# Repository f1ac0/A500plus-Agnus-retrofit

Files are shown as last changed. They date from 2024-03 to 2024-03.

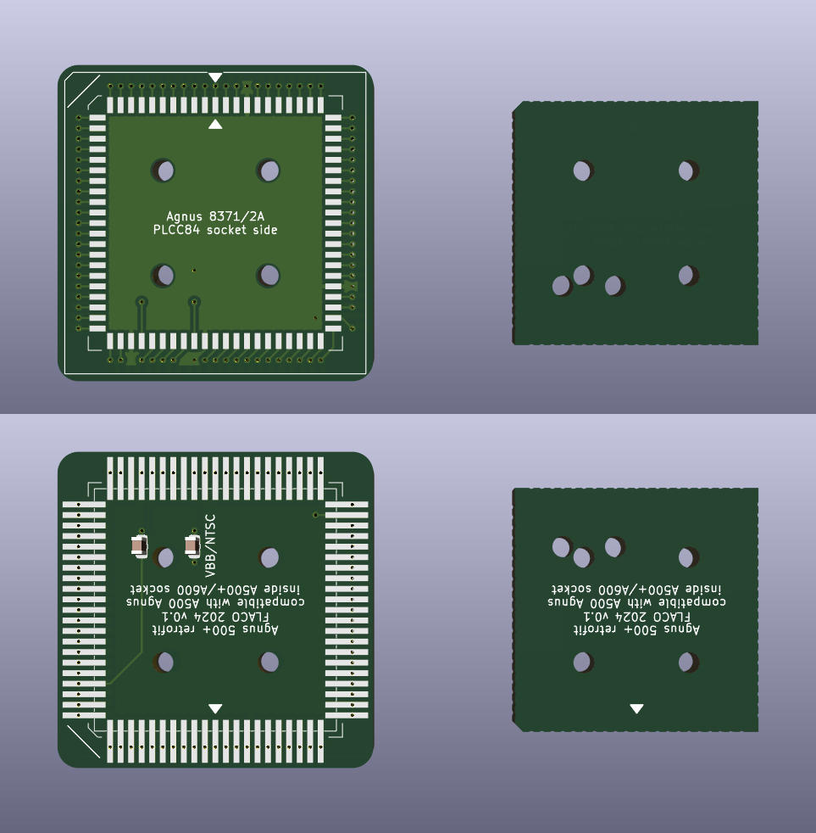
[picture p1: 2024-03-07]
SMD socket version/A500+ Agnus retrofit SMD - FLACO 2024.jpg

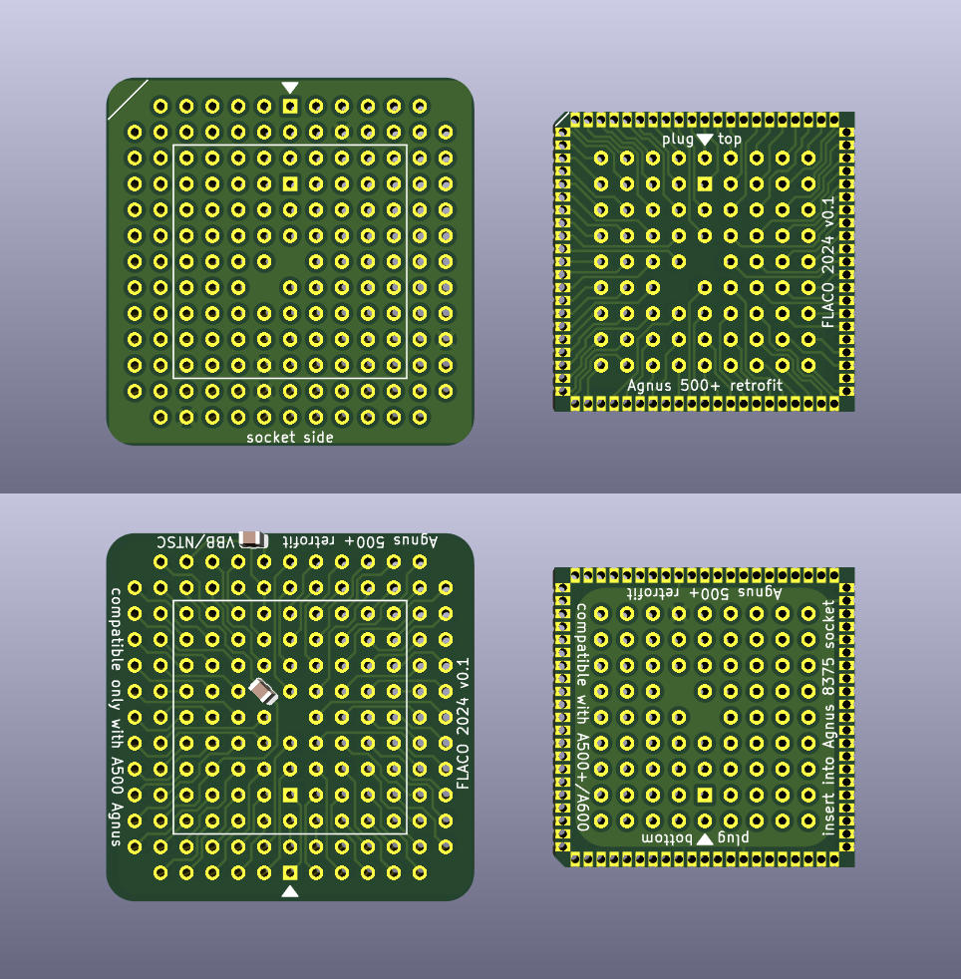
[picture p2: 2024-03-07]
TH socket version/A500+ Agnus retrofit TH - FLACO 2024.jpg

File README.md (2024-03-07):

# A500+ Agnus retrofit
I accidentally zapped my precious 8375 Agnus with ESD on my A500(+) rev8 motherboard, and I am planing to use a cheaper 8371 to continue the development of the Pistorm'X500 and other Amiga projects.

It is based on the same idea as the DietAgnus https://github.com/LIV2/Diet-Agnus-A500-plus except I plan to keep the PLCC84 socket to restore the original system later on. I am also looking forward modern replacement projects such as the ReAgnus https://github.com/jbilander/ReAgnus or https://github.com/jbilander/ReAgnus-MegAChip.

There are two versions in this repository :
- The Through Hole version was the first one I designed : it is based on a TH PLCC84 socket connected to a "plug" PCB using standard 2.54mm pin headers ; to ensure the contact with the motherboard socket, the plug PCB needs to mimic the PLCC "legs" with the addition of single core wires soldered from each top pad to its bottom counterpart all around the edges.
- The SMD version uses a SMD PLCC84 socket ; four strips of 1.27mm angled pin headers with a 0.46mm square section are used as contacts to the motherboard socket ; the spacer PCB(s) should help to solder the pins in place, push them on the contacts of the motherboard socket, and make it rigid enough to stay in place (stack two or 3 and glue them together).

These are not tested yet.

# Disclaimer
This is a hobbyist project, it comes with no warranty and no support. Also remember that the Amiga machines are about 30 years old and may fail because of such hardware expansions.

There are many Agnus versions and Amiga motherboards, so you really should look for information about the specific parts you plan to use.

I publish my work under the CC-BY-NC-SA license.

If you find it useful and want to reward my hard work : I am always looking for Amiga/Atari/Amstrad/Commodore/Sinclair/Thomson... to repair and hack, please contact me.

# Making it
Pull _XCLKEN to 5V using either a solder blob or a resistor.

If your Agnus is marked with VBB, install a 0.1uF ceramic cap on the TEST/VBB pin. Otherwise it may be closed to switch to NTSC.

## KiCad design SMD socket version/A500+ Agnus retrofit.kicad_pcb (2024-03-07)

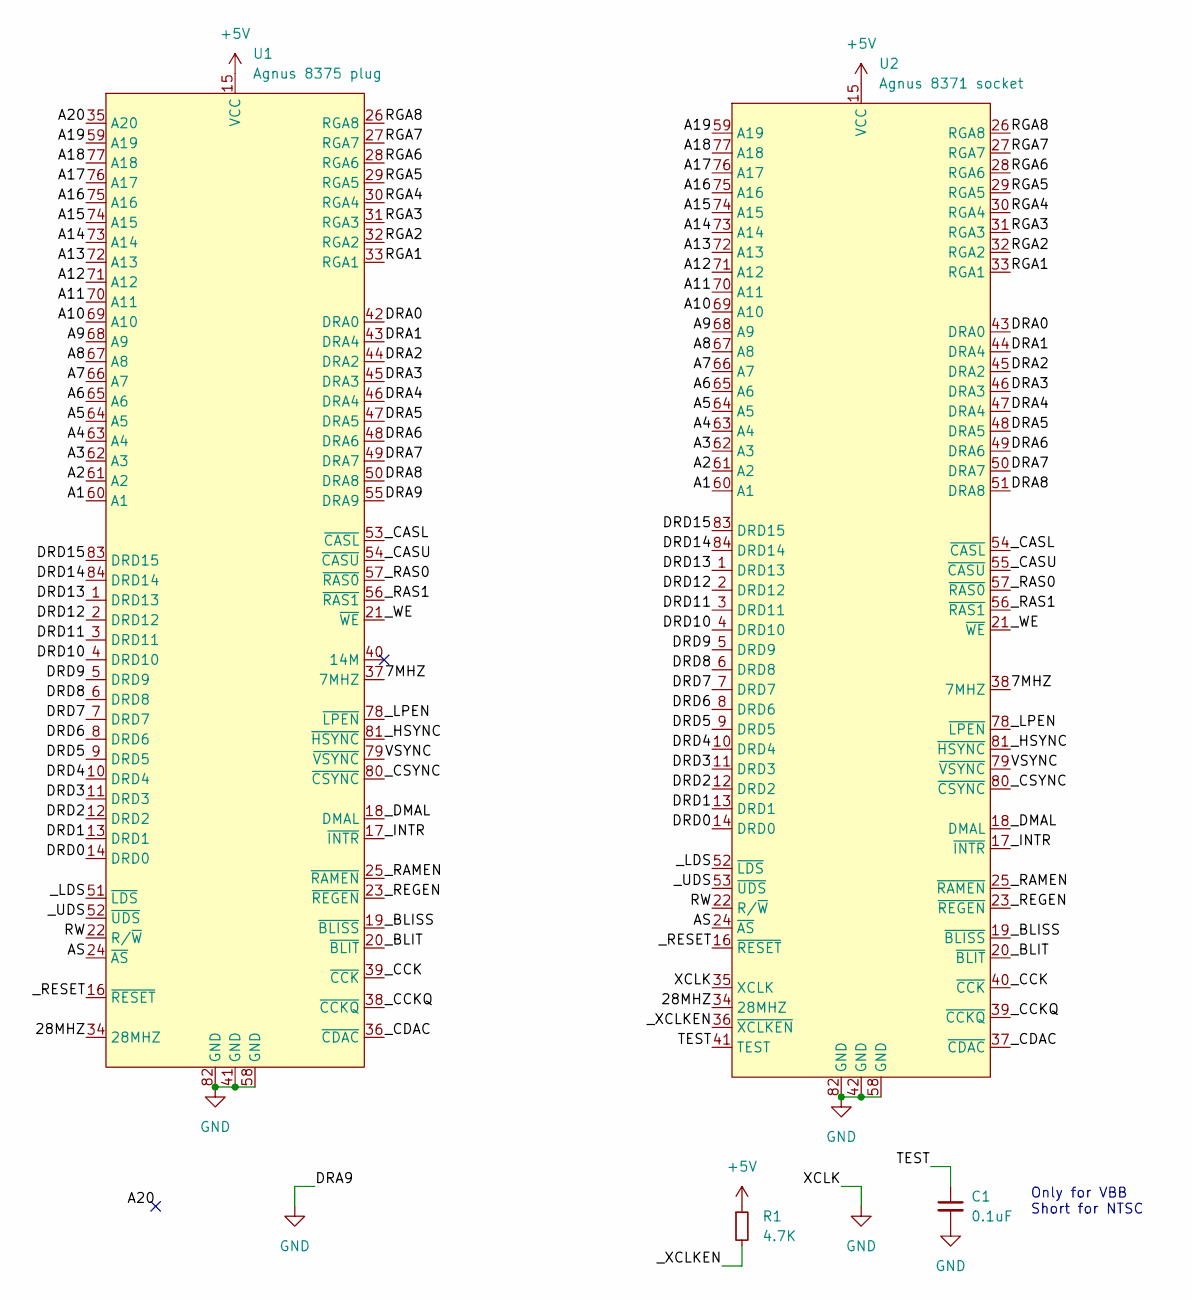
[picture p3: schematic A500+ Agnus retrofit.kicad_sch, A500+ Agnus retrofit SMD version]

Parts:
C1: 0.1uF; C_0805_2012Metric_shortable
R1: 4.7K; C_0805_2012Metric_shortable
U1: Agnus 8375 plug; PLCC-84_SMD-Plug
U2: Agnus 8371 socket; PLCC-84_SMD-Socket

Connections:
+5V: R1.1, U1.15 (VCC), U2.15 (VCC)
/7MHZ: U1.37 (7MHZ), U2.38 (7MHZ)
/28MHZ: U1.34 (28MHZ), U2.34 (28MHZ)
/A1: U1.60 (A1), U2.60 (A1)
/A2: U1.61 (A2), U2.61 (A2)
/A3: U1.62 (A3), U2.62 (A3)
/A4: U1.63 (A4), U2.63 (A4)
/A5: U1.64 (A5), U2.64 (A5)
/A6: U1.65 (A6), U2.65 (A6)
/A7: U1.66 (A7), U2.66 (A7)
/A8: U1.67 (A8), U2.67 (A8)
/A9: U1.68 (A9), U2.68 (A9)
/A10: U1.69 (A10), U2.69 (A10)
/A11: U1.70 (A11), U2.70 (A11)
/A12: U1.71 (A12), U2.71 (A12)
/A13: U1.72 (A13), U2.72 (A13)
/A14: U1.73 (A14), U2.73 (A14)
/A15: U1.74 (A15), U2.74 (A15)
/A16: U1.75 (A16), U2.75 (A16)
/A17: U1.76 (A17), U2.76 (A17)
/A18: U1.77 (A18), U2.77 (A18)
/A19: U1.59 (A19), U2.59 (A19)
/A20: U1.35 (A20)
/AS: U1.24 (~AS), U2.24 (~AS)
/DRA0: U1.42 (DRA0), U2.43 (DRA0)
/DRA1: U1.43 (DRA4), U2.44 (DRA4)
/DRA2: U1.44 (DRA2), U2.45 (DRA2)
/DRA3: U1.45 (DRA3), U2.46 (DRA3)
/DRA4: U1.46 (DRA4), U2.47 (DRA4)
/DRA5: U1.47 (DRA5), U2.48 (DRA5)
/DRA6: U1.48 (DRA6), U2.49 (DRA6)
/DRA7: U1.49 (DRA7), U2.50 (DRA7)
/DRA8: U1.50 (DRA8), U2.51 (DRA8)
/DRD0: U1.14 (DRD0), U2.14 (DRD0)
/DRD1: U1.13 (DRD1), U2.13 (DRD1)
/DRD2: U1.12 (DRD2), U2.12 (DRD2)
/DRD3: U1.11 (DRD3), U2.11 (DRD3)
/DRD4: U1.10 (DRD4), U2.10 (DRD4)
/DRD5: U1.9 (DRD5), U2.9 (DRD5)
/DRD6: U1.8 (DRD6), U2.8 (DRD6)
/DRD7: U1.7 (DRD7), U2.7 (DRD7)
/DRD8: U1.6 (DRD8), U2.6 (DRD8)
/DRD9: U1.5 (DRD9), U2.5 (DRD9)
/DRD10: U1.4 (DRD10), U2.4 (DRD10)
/DRD11: U1.3 (DRD11), U2.3 (DRD11)
/DRD12: U1.2 (DRD12), U2.2 (DRD12)
/DRD13: U1.1 (DRD13), U2.1 (DRD13)
/DRD14: U1.84 (DRD14), U2.84 (DRD14)
/DRD15: U1.83 (DRD15), U2.83 (DRD15)
/RGA1: U1.33 (RGA1), U2.33 (RGA1)
/RGA2: U1.32 (RGA2), U2.32 (RGA2)
/RGA3: U1.31 (RGA3), U2.31 (RGA3)
/RGA4: U1.30 (RGA4), U2.30 (RGA4)
/RGA5: U1.29 (RGA5), U2.29 (RGA5)
/RGA6: U1.28 (RGA6), U2.28 (RGA6)
/RGA7: U1.27 (RGA7), U2.27 (RGA7)
/RGA8: U1.26 (RGA8), U2.26 (RGA8)
/RW: U1.22 (R/~W), U2.22 (R/~W)
/TEST: C1.1, U2.41 (TEST)
/VSYNC: U1.79 (~VSYNC), U2.79 (~VSYNC)
/_BLISS: U1.19 (~BLISS), U2.19 (~BLISS)
/_BLIT: U1.20 (~BLIT), U2.20 (~BLIT)
/_CASL: U1.53 (~CASL), U2.54 (~CASL)
/_CASU: U1.54 (~CASU), U2.55 (~CASU)
/_CCK: U1.39 (~CCK), U2.40 (~CCK)
/_CCKQ: U1.38 (~CCKQ), U2.39 (~CCKQ)
/_CDAC: U1.36 (~CDAC), U2.37 (~CDAC)
/_CSYNC: U1.80 (~CSYNC), U2.80 (~CSYNC)
/_DMAL: U1.18 (DMAL), U2.18 (DMAL)
/_HSYNC: U1.81 (~HSYNC), U2.81 (~HSYNC)
/_INTR: U1.17 (~INTR), U2.17 (~INTR)
/_LDS: U1.51 (~LDS), U2.52 (~LDS)
/_LPEN: U1.78 (~LPEN), U2.78 (~LPEN)
/_RAMEN: U1.25 (~RAMEN), U2.25 (~RAMEN)
/_RAS0: U1.57 (~RAS0), U2.57 (~RAS0)
/_RAS1: U1.56 (~RAS1), U2.56 (~RAS1)
/_REGEN: U1.23 (~REGEN), U2.23 (~REGEN)
/_RESET: U1.16 (~RESET), U2.16 (~RESET)
/_UDS: U1.52 (~UDS), U2.53 (~UDS)
/_WE: U1.21 (~WE), U2.21 (~WE)
/_XCLKEN: R1.2, U2.36 (~XCLKEN)
GND: C1.2, U1.41 (GND), U1.55 (DRA9), U1.58 (GND), U1.82 (GND), U2.35 (XCLK), U2.42 (GND), U2.58 (GND), U2.82 (GND)

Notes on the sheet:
Only for VBB Short for NTSC

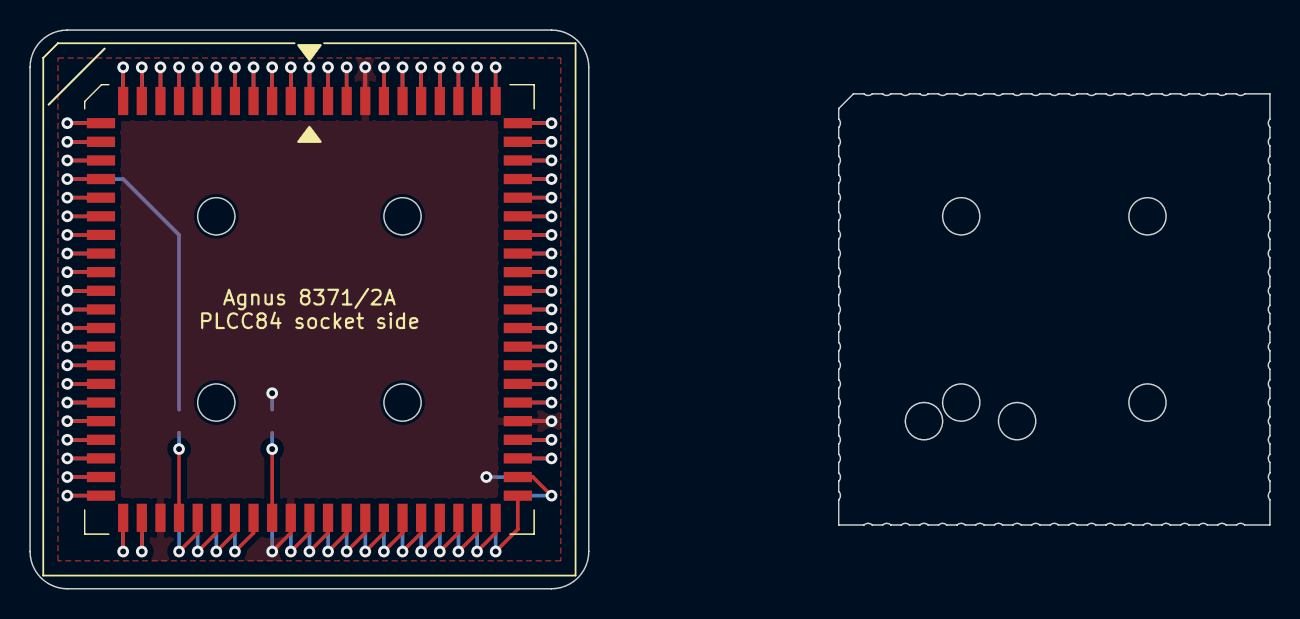
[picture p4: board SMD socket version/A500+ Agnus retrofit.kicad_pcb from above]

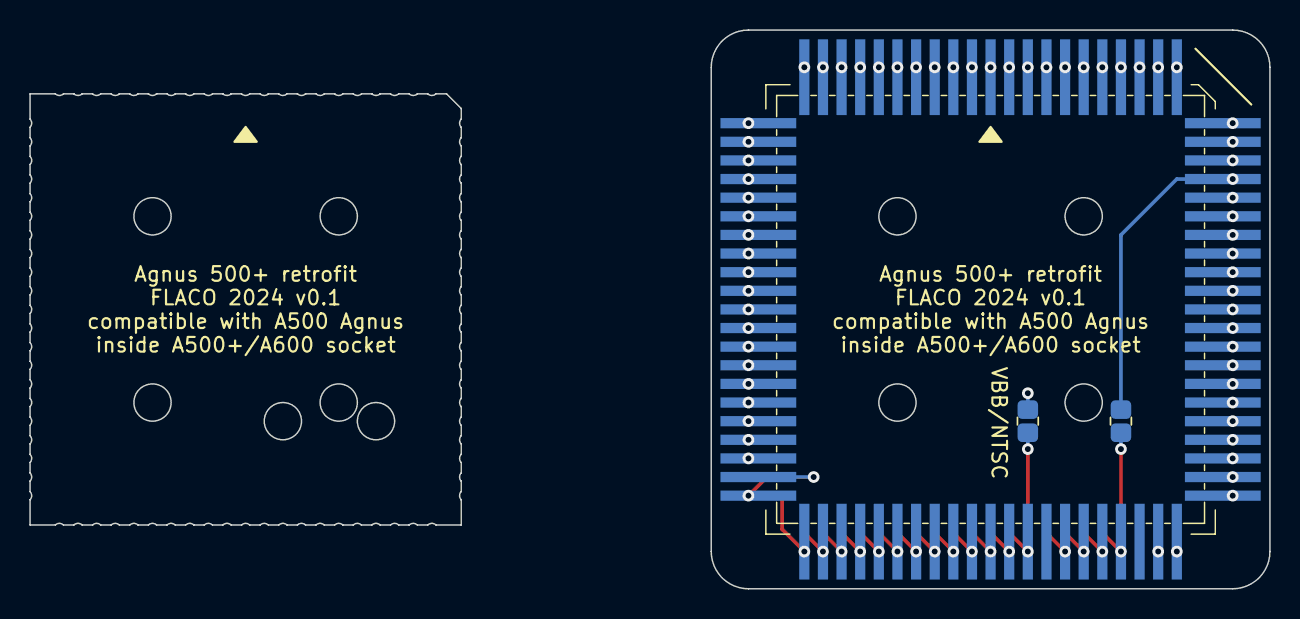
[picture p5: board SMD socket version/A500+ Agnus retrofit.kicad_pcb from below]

Board: 2 copper layers, 38.1 x 38.1 mm, 4 parts (3 on the bottom side), 81 nets.

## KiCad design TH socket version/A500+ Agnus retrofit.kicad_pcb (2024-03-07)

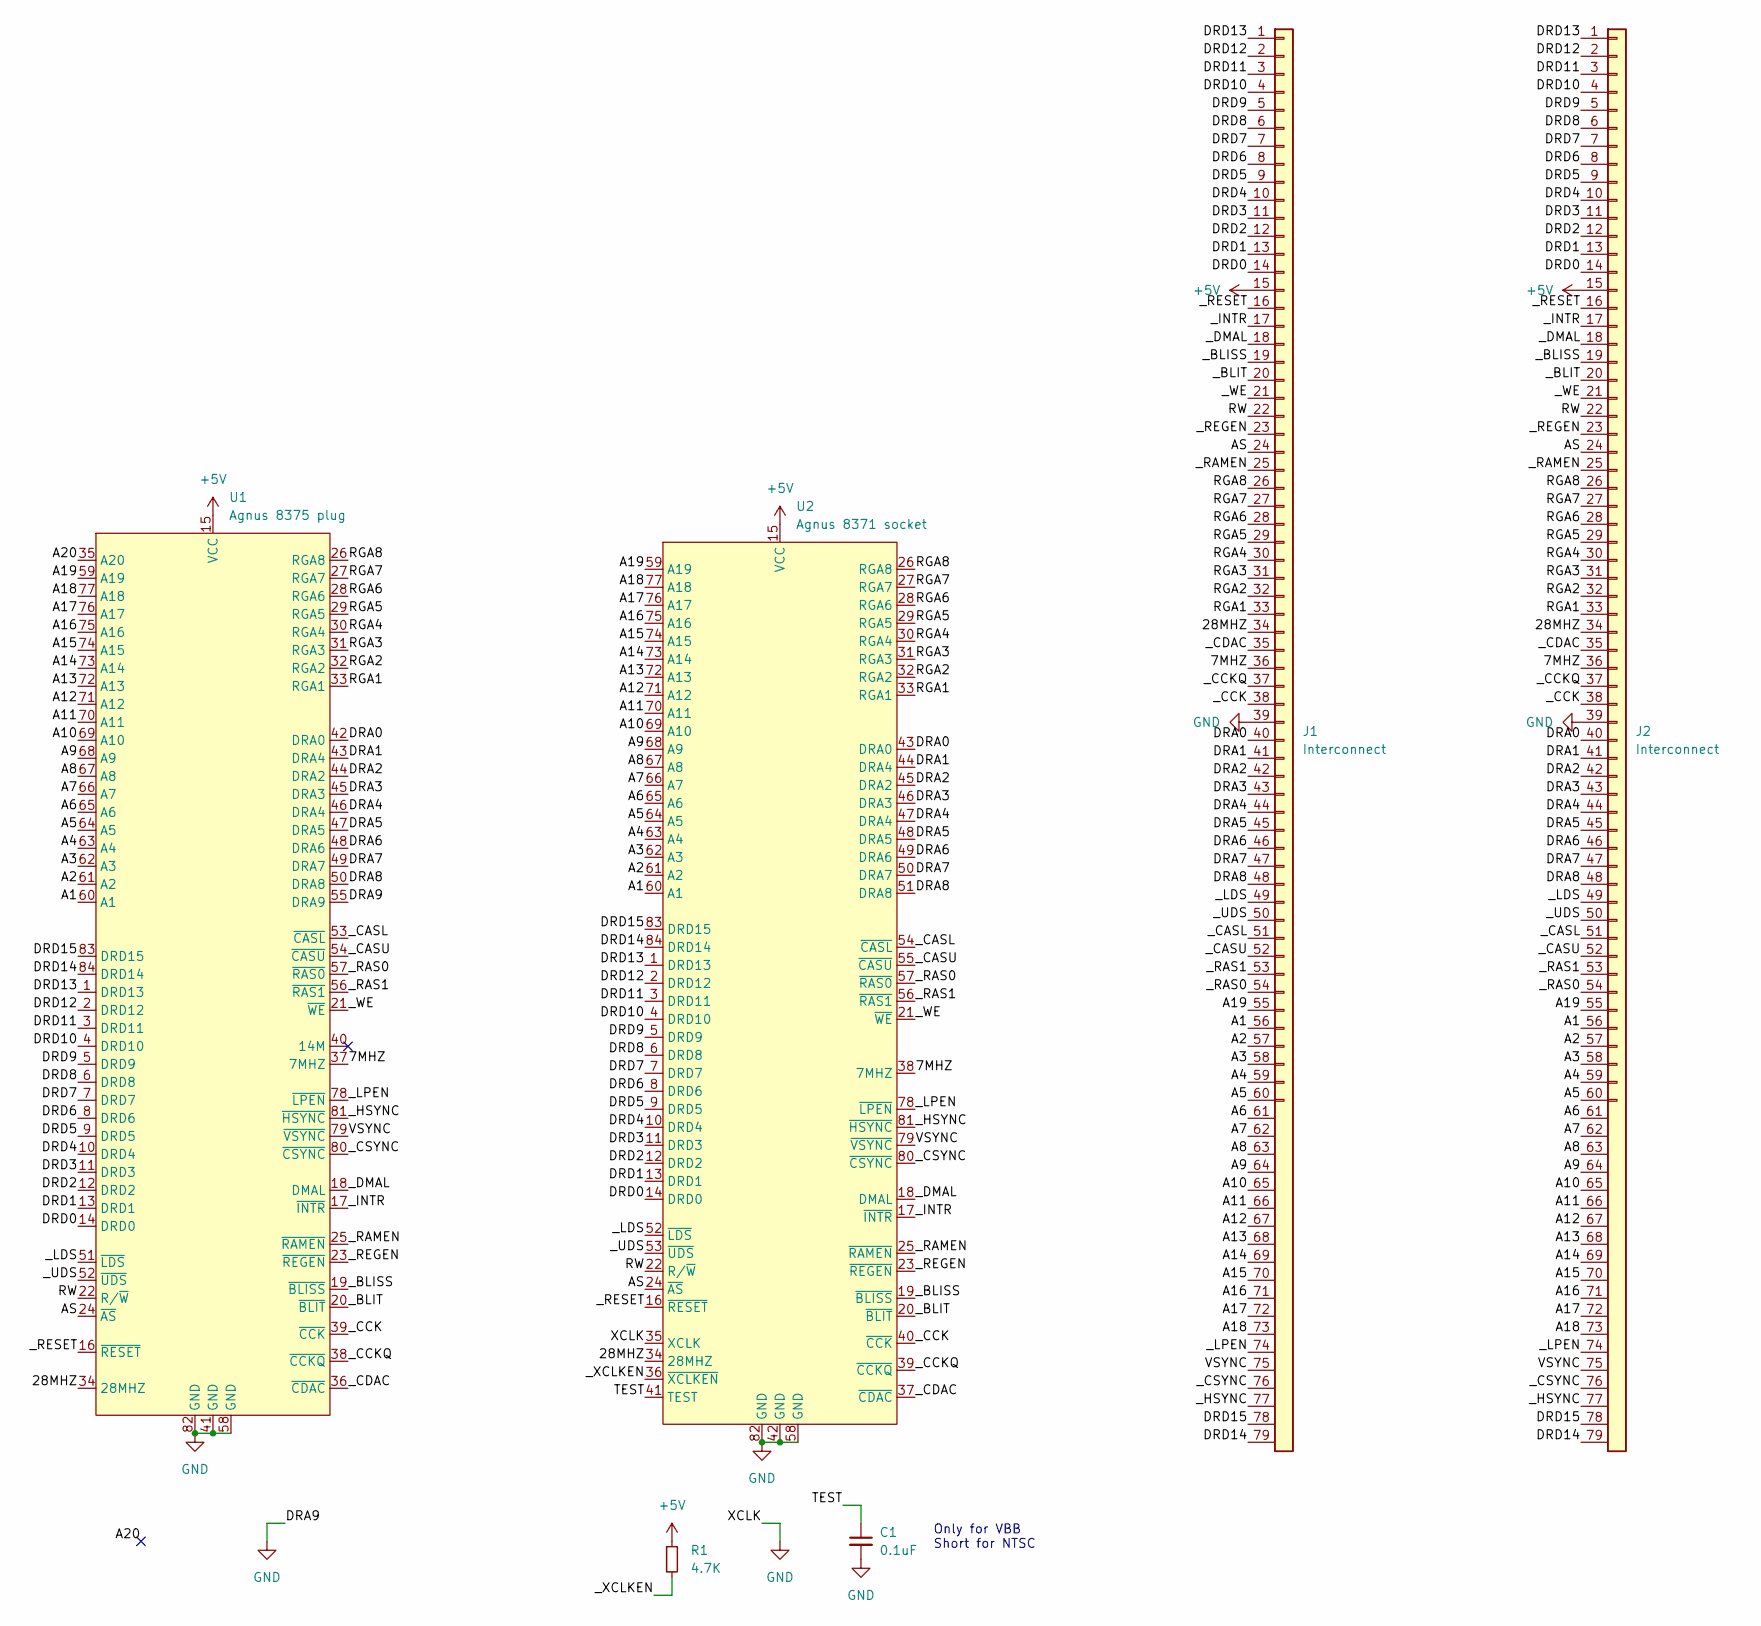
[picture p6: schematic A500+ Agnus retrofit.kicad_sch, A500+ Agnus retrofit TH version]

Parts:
C1: 0.1uF; C_0805_2012Metric_shortable
J1, J2: Interconnect; A500+_Agnus_retrofit_interconnect
R1: 4.7K; C_0805_2012Metric_shortable
U1: Agnus 8375 plug; A500+_Agnus_retrofit_plug
U2: Agnus 8371 socket; PLCC-84_THT-Socket

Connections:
+5V: J1.15, J2.15, R1.1, U1.15 (VCC), U2.15 (VCC)
/7MHZ: J1.36, J2.36, U1.37 (7MHZ), U2.38 (7MHZ)
/28MHZ: J1.34, J2.34, U1.34 (28MHZ), U2.34 (28MHZ)
/A1: J1.56, J2.56, U1.60 (A1), U2.60 (A1)
/A2: J1.57, J2.57, U1.61 (A2), U2.61 (A2)
/A3: J1.58, J2.58, U1.62 (A3), U2.62 (A3)
/A4: J1.59, J2.59, U1.63 (A4), U2.63 (A4)
/A5: J1.60, J2.60, U1.64 (A5), U2.64 (A5)
/A6: J1.61 (Pin_41), J2.61 (Pin_41), U1.65 (A6), U2.65 (A6)
/A7: J1.62 (Pin_42), J2.62 (Pin_42), U1.66 (A7), U2.66 (A7)
/A8: J1.63 (Pin_43), J2.63 (Pin_43), U1.67 (A8), U2.67 (A8)
/A9: J1.64 (Pin_44), J2.64 (Pin_44), U1.68 (A9), U2.68 (A9)
/A10: J1.65 (Pin_45), J2.65 (Pin_45), U1.69 (A10), U2.69 (A10)
/A11: J1.66 (Pin_46), J2.66 (Pin_46), U1.70 (A11), U2.70 (A11)
/A12: J1.67 (Pin_47), J2.67 (Pin_47), U1.71 (A12), U2.71 (A12)
/A13: J1.68 (Pin_48), J2.68 (Pin_48), U1.72 (A13), U2.72 (A13)
/A14: J1.69 (Pin_49), J2.69 (Pin_49), U1.73 (A14), U2.73 (A14)
/A15: J1.70 (Pin_50), J2.70 (Pin_50), U1.74 (A15), U2.74 (A15)
/A16: J1.71 (Pin_51), J2.71 (Pin_51), U1.75 (A16), U2.75 (A16)
/A17: J1.72 (Pin_52), J2.72 (Pin_52), U1.76 (A17), U2.76 (A17)
/A18: J1.73 (Pin_53), J2.73 (Pin_53), U1.77 (A18), U2.77 (A18)
/A19: J1.55, J2.55, U1.59 (A19), U2.59 (A19)
/A20: U1.35 (A20)
/AS: J1.24, J2.24, U1.24 (~AS), U2.24 (~AS)
/DRA0: J1.40, J2.40, U1.42 (DRA0), U2.43 (DRA0)
/DRA1: J1.41, J2.41, U1.43 (DRA4), U2.44 (DRA4)
/DRA2: J1.42, J2.42, U1.44 (DRA2), U2.45 (DRA2)
/DRA3: J1.43, J2.43, U1.45 (DRA3), U2.46 (DRA3)
/DRA4: J1.44, J2.44, U1.46 (DRA4), U2.47 (DRA4)
/DRA5: J1.45, J2.45, U1.47 (DRA5), U2.48 (DRA5)
/DRA6: J1.46, J2.46, U1.48 (DRA6), U2.49 (DRA6)
/DRA7: J1.47, J2.47, U1.49 (DRA7), U2.50 (DRA7)
/DRA8: J1.48, J2.48, U1.50 (DRA8), U2.51 (DRA8)
/DRD0: J1.14, J2.14, U1.14 (DRD0), U2.14 (DRD0)
/DRD1: J1.13, J2.13, U1.13 (DRD1), U2.13 (DRD1)
/DRD2: J1.12, J2.12, U1.12 (DRD2), U2.12 (DRD2)
/DRD3: J1.11, J2.11, U1.11 (DRD3), U2.11 (DRD3)
/DRD4: J1.10, J2.10, U1.10 (DRD4), U2.10 (DRD4)
/DRD5: J1.9, J2.9, U1.9 (DRD5), U2.9 (DRD5)
/DRD6: J1.8, J2.8, U1.8 (DRD6), U2.8 (DRD6)
/DRD7: J1.7, J2.7, U1.7 (DRD7), U2.7 (DRD7)
/DRD8: J1.6, J2.6, U1.6 (DRD8), U2.6 (DRD8)
/DRD9: J1.5, J2.5, U1.5 (DRD9), U2.5 (DRD9)
/DRD10: J1.4, J2.4, U1.4 (DRD10), U2.4 (DRD10)
/DRD11: J1.3, J2.3, U1.3 (DRD11), U2.3 (DRD11)
/DRD12: J1.2, J2.2, U1.2 (DRD12), U2.2 (DRD12)
/DRD13: J1.1, J2.1, U1.1 (DRD13), U2.1 (DRD13)
/DRD14: J1.79 (Pin_58), J2.79 (Pin_58), U1.84 (DRD14), U2.84 (DRD14)
/DRD15: J1.78 (Pin_58), J2.78 (Pin_58), U1.83 (DRD15), U2.83 (DRD15)
/RGA1: J1.33, J2.33, U1.33 (RGA1), U2.33 (RGA1)
/RGA2: J1.32, J2.32, U1.32 (RGA2), U2.32 (RGA2)
/RGA3: J1.31, J2.31, U1.31 (RGA3), U2.31 (RGA3)
/RGA4: J1.30, J2.30, U1.30 (RGA4), U2.30 (RGA4)
/RGA5: J1.29, J2.29, U1.29 (RGA5), U2.29 (RGA5)
/RGA6: J1.28, J2.28, U1.28 (RGA6), U2.28 (RGA6)
/RGA7: J1.27, J2.27, U1.27 (RGA7), U2.27 (RGA7)
/RGA8: J1.26, J2.26, U1.26 (RGA8), U2.26 (RGA8)
/RW: J1.22, J2.22, U1.22 (R/~W), U2.22 (R/~W)
/TEST: C1.1, U2.41 (TEST)
/VSYNC: J1.75 (Pin_55), J2.75 (Pin_55), U1.79 (~VSYNC), U2.79 (~VSYNC)
/_BLISS: J1.19, J2.19, U1.19 (~BLISS), U2.19 (~BLISS)
/_BLIT: J1.20, J2.20, U1.20 (~BLIT), U2.20 (~BLIT)
/_CASL: J1.51, J2.51, U1.53 (~CASL), U2.54 (~CASL)
/_CASU: J1.52, J2.52, U1.54 (~CASU), U2.55 (~CASU)
/_CCK: J1.38, J2.38, U1.39 (~CCK), U2.40 (~CCK)
/_CCKQ: J1.37, J2.37, U1.38 (~CCKQ), U2.39 (~CCKQ)
/_CDAC: J1.35, J2.35, U1.36 (~CDAC), U2.37 (~CDAC)
/_CSYNC: J1.76 (Pin_56), J2.76 (Pin_56), U1.80 (~CSYNC), U2.80 (~CSYNC)
/_DMAL: J1.18, J2.18, U1.18 (DMAL), U2.18 (DMAL)
/_HSYNC: J1.77 (Pin_57), J2.77 (Pin_57), U1.81 (~HSYNC), U2.81 (~HSYNC)
/_INTR: J1.17, J2.17, U1.17 (~INTR), U2.17 (~INTR)
/_LDS: J1.49, J2.49, U1.51 (~LDS), U2.52 (~LDS)
/_LPEN: J1.74 (Pin_54), J2.74 (Pin_54), U1.78 (~LPEN), U2.78 (~LPEN)
/_RAMEN: J1.25, J2.25, U1.25 (~RAMEN), U2.25 (~RAMEN)
/_RAS0: J1.54, J2.54, U1.57 (~RAS0), U2.57 (~RAS0)
/_RAS1: J1.53, J2.53, U1.56 (~RAS1), U2.56 (~RAS1)
/_REGEN: J1.23, J2.23, U1.23 (~REGEN), U2.23 (~REGEN)
/_RESET: J1.16, J2.16, U1.16 (~RESET), U2.16 (~RESET)
/_UDS: J1.50, J2.50, U1.52 (~UDS), U2.53 (~UDS)
/_WE: J1.21, J2.21, U1.21 (~WE), U2.21 (~WE)
/_XCLKEN: R1.2, U2.36 (~XCLKEN)
GND: C1.2, J1.39, J2.39, U1.41 (GND), U1.55 (DRA9), U1.58 (GND), U1.82 (GND), U2.35 (XCLK), U2.42 (GND), U2.58 (GND), U2.82 (GND)

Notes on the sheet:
Only for VBB Short for NTSC

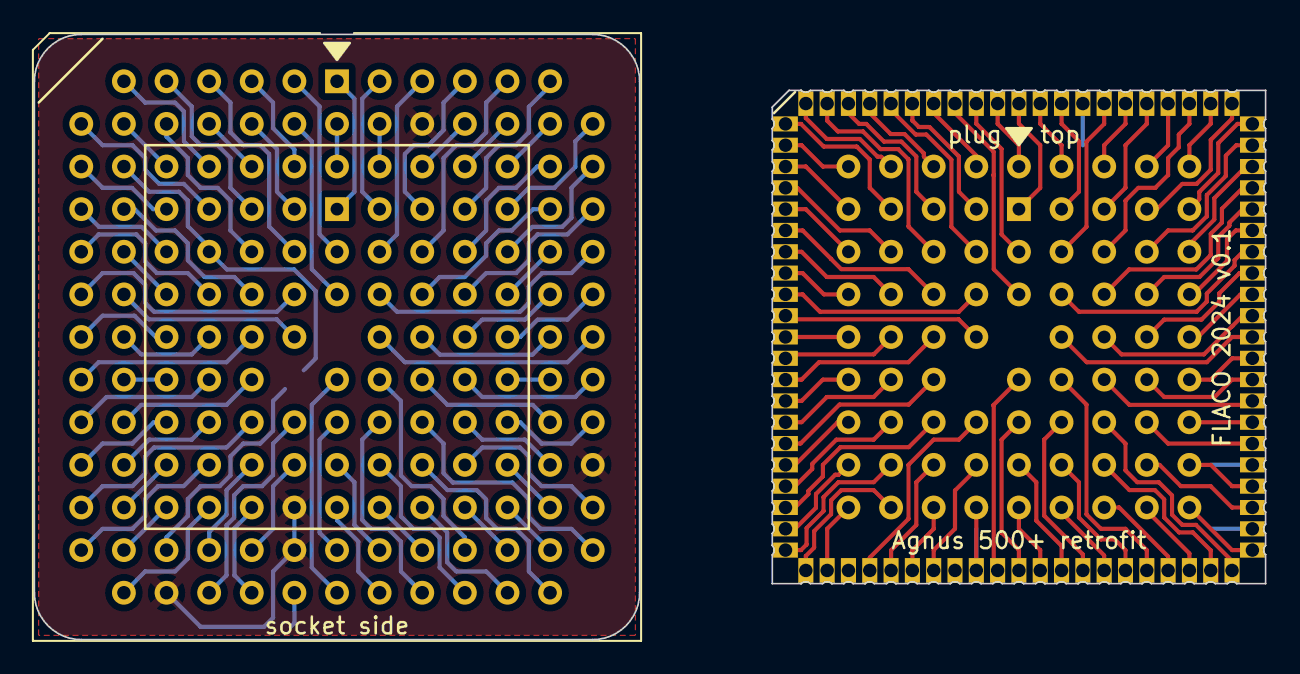
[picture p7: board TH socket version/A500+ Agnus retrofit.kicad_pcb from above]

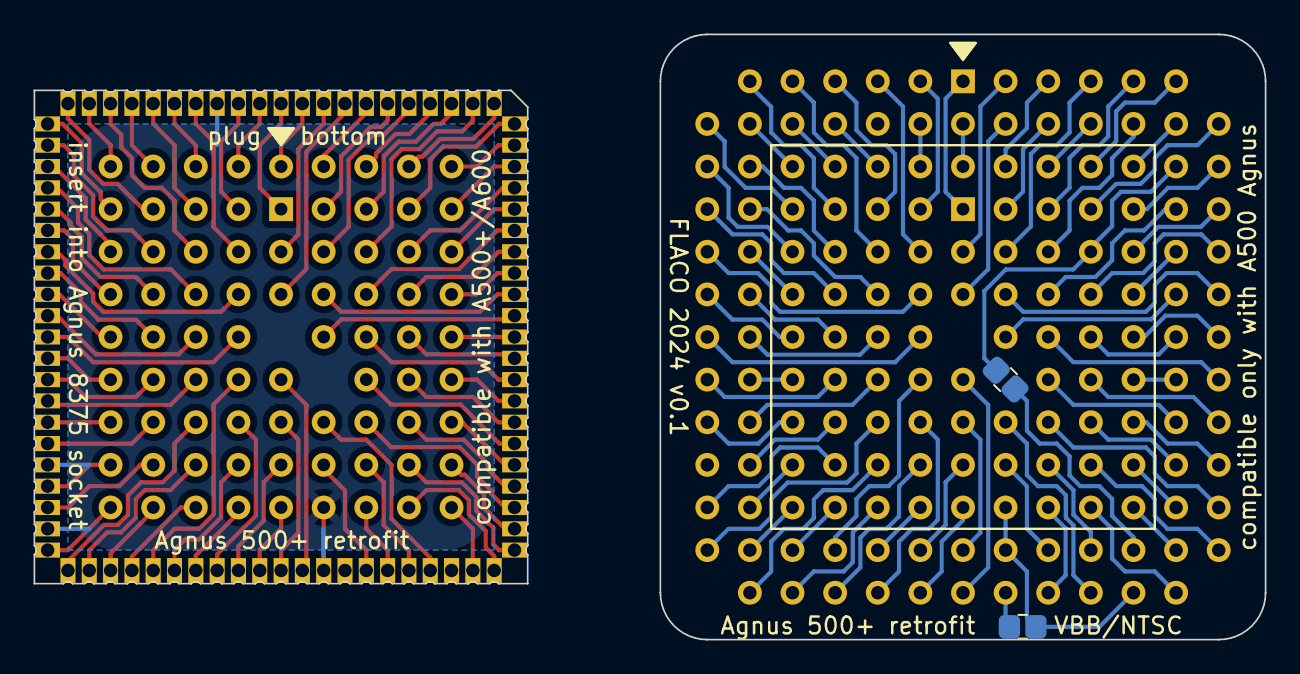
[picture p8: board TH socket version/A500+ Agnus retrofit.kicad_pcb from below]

Board: 2 copper layers, 73.4 x 36.1 mm, 6 parts (2 on the bottom side), 81 nets.

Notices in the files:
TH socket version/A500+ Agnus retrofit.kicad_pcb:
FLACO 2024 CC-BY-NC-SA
